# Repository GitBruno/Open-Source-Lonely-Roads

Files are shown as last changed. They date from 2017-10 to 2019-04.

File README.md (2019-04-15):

# Open Source Lonely Roads
An active linear power distribution board for Eurorack.

> __WARNING!__ ⚡️ Please be aware of the risks associated with electronics and take relevant precautions.

## Features
- High voltage distribution boards
- Dedicated linear regulators for each header
- Switchable status LEDs
- Star grounding on dedicated layer
- Wide traces
- Reverse voltage protection
- Bypass capacitors
- Ultra low noise
- Ultra low inter-module noise
- Protection + safety features
- 3u boat compatible
- Standard 84hp (19”) and 104hp compatible
- Wide range of voltage input options
- Multiple CV/Gate busses possible. (Have conflicting modules play nice together)
- Optional addons (Voltage converter/startup delay)

Please read the [Wiki](https://github.com/GitBruno/Open-Source-Lonely-Roads/wiki) to find out more about this project.

## Licence
Open Source Lonely Roads by [Robert D Jordan](http://www.catfullofghosts.com/) and [Bruno Herfst](http://brunoherfst.com/) is licensed under a [Creative Commons Attribution 4.0 International License](LICENCE.md).



WaveGuides

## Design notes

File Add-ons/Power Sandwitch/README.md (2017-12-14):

# Power Sandwitch
An add-on for the Open Source Lonely Roads power distribution boards. This add-on makes the OSLR boards eat a wide variety of power supplies. 

So besides any +- 15v cage power supply the OSLR can be powered off:

- Single 9-18v DC supply
- Dual 15+v DC supplies (E.g. 2 laptop chargers)
- Single 14-36v supply (Cheap!)

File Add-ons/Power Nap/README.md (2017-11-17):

# Power Nap
An add-on for the Open Source Lonely Roads power distribution boards. This add-on adds a 555 timer circuit to delay startup time.

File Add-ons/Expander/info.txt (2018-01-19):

An expander for the Lonely Roads that breaks out each individual eurorack power header into 2 right angle 16pin
and one vertical 10pin header. Attaches ontop of Lonely Roads busboard like an arduino sheild.
Each set of 3 power headers is isolated from all others.

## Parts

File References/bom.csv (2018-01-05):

Qty | Part Number | Description | Package | Manufacturer | Suggested Suppliers | Mouser Part No | Sub/Comments | Part ID.
6 |  | Headers | 2X08 |  |  | 538-15-47-7616 |  | JP1,JP2,JP3,JP4,JP5,JP6
6 | 7805 | Voltage Regulator | 78MXXS |  |  | 511-L7805CV |  | 7805,2,5,8,11,14
6 | 7812 | Voltage Regulator | 78MXXS |  |  | 511-L7812CV |  | 7812,1,4,7,10,13
6 | 7912 | Voltage Regulator | 79XXS |  |  | 926-LM7912CT/NOPB |  | 3,6,9,12,15,7912
6 | 220 | Resistor |  |  |  | 660-MF1/4LCT52R221J | 1/4w | R1,R4,R7,R10,R13,R16
12 | 550 | Resistor |  |  |  | 660-MF1/4LCT52R511J | Arround 500/510 is fine too | R2,R3,R5,R6,R8,R9,R11,R12,R14,R15,R17,R18
3 |  | Terminal |  |  |  |  | need Mouser Part No equivilent | SCREW_+15,SCREW_-15,SCREW_GND
18 | 0.1uf | Capacitor |  |  |  | 75-1C20X7R103K050B |  | C1,C2,C3,C6,C7,C12,C13,C14,C15,C19,C20,C21,C24,C25,C26,C29,C30,C31
12 | 10uf | Capacitor | CPOL-RADIAL-10UF-25V |  |  | 647-UPW1E100MDD6 |  | C4,C5,C8,C9,C16,C17,C22,C23,C27,C28,C32,C33
3 | 100uf | Capacitor | CPOL-RADIAL-100UF-25V |  |  | 647-UVY1E101MDD | board needs better spacing for these | C10,C11,C18
12 | 1N4004 | Diode | DO41-10 |  |  | 621-1N4004 |  | D1,D2,D3,D4,D7,D8,D9,D10,D11,D12,D13,D14
1 |  | Switch | EG1218 |  |  | 612-EG1218 | can just use a piece of wire if you don't need to turn the on and off. | S1
3 | PIN2F061.200 | Terminal | F061.200 |  |  | 571-624091 |  | J1_+15,J2_+15,J3_GND,J4_GND,J5_-15,J6_-15
18 |  | LED | LED3MM |  |  | 696-SSF-LX3P74GD | Use 3 colours one for +12v, -12v and 5v | LED1,LED2,LED3,LED4,LED5,LED6,LED7,LED8,LED9,LED10,LED11,LED12,LED13,LED14,LED15,LED16,LED17,LED18
2 | BA296 | Rectifier | P2-15 |  |  | 833-1N5400-TP |  | D5,D6
2 | PTCPTH | Reseting Fuse | PTC |  |  | 652-MF-R300-2 |  | F1,F2
2 |  | Ferrite Beads 7A Leaded EMIFIL | RLB0912 |  |  | 81-BL02RN2R1M2B |  | U$1,U$2
3 |  | Terminals 6.3MM VERT PCB SPD TERM-10K/RL |  |  |  | 855-S409-46 |  | J1_+15,J2_+15,J3_GND,J4_GND,J5_-15,J6_-15
? |  | 6.3mm Female Spade Crimp |  |  |  | 517-7250 | connectors used to link busboards together, or link to power supply

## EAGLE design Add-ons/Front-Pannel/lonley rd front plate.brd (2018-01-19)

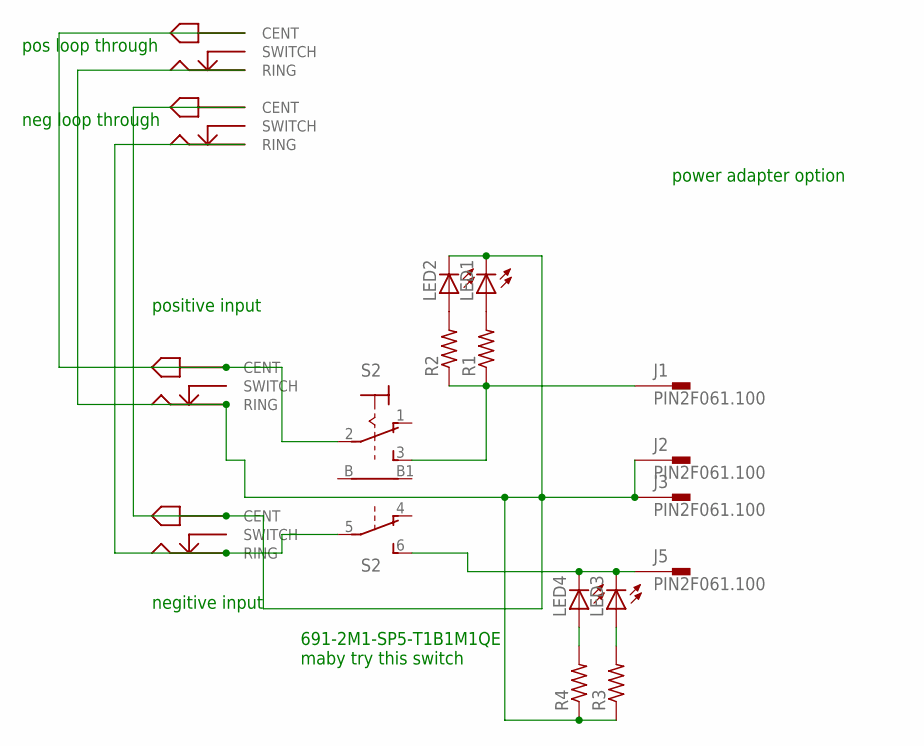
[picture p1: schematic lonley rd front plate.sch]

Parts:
J1, J2, J3, J5: PIN2F061.100; F061.100
LED1, LED2, LED3, LED4: LED3MM
R1, R2, R3, R4: R-US_0309/V; 0309V
S2: 9070-2W
U$1, U$2, U$3, U$4: PJ-066A_DC_JACK

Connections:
unnamed: LED2.A, R2.2
unnamed: J2.A1, J2.A2, J3.A1, J3.A2, LED1.K (C), LED2.K (C), R3.1, R4.1, U$1.RING, U$2.CENT, U$3.RING, U$4.CENT
unnamed: J1.A1, J1.A2, R1.1, R2.1, S2.3 (S)
unnamed: J5.A1, J5.A2, LED3.K (C), LED4.K (C)
unnamed: S2.2, U$1.CENT, U$3.CENT
unnamed: U$2.RING, U$4.RING
unnamed: LED1.A, R1.2
unnamed: LED3.A, R3.2
unnamed: LED4.A, R4.2

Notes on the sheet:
positive input
negitive input
pos loop through
neg loop through
691-2M1-SP5-T1B1M1QE maby try this switch
power adapter option

Board: 2 copper layers, 17 parts (0 on the bottom side), 9 nets, no tracks yet.

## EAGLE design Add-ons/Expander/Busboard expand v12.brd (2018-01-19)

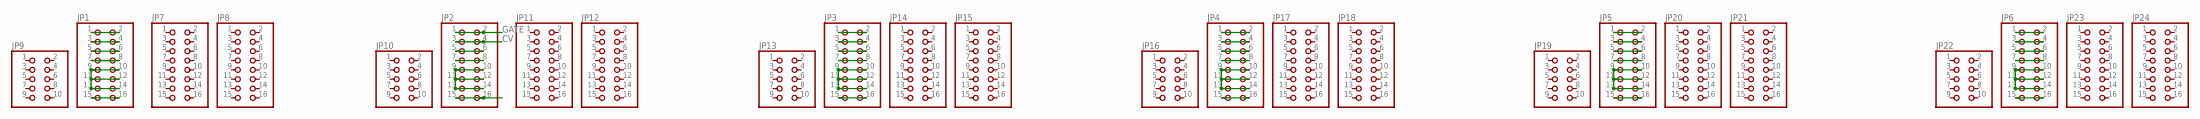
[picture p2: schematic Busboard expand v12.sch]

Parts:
JP1, JP2, JP3, JP4, JP5, JP6: PINHD-2X8; 2X08
JP7, JP8, JP11, JP12, JP14, JP15, JP17, JP18, JP20, JP21, JP23, JP24: PINHD-2X8/90; 2X08/90
JP9, JP10, JP13, JP16, JP19, JP22: PINHD-2X5; 2X05

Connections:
CV: JP1.3, JP1.4, JP2.3, JP2.4, JP3.3, JP3.4, JP4.3, JP4.4, JP5.3, JP5.4, JP6.3, JP6.4
GATE: JP1.1, JP1.2, JP2.1, JP2.2, JP3.1, JP3.2, JP4.1, JP4.2, JP5.1, JP5.2, JP6.1, JP6.2
unnamed: JP2.9, JP2.10, JP2.11, JP2.12, JP2.13, JP2.14
unnamed: JP3.9, JP3.10, JP3.11, JP3.12, JP3.13, JP3.14
unnamed: JP1.9, JP1.10, JP1.11, JP1.12, JP1.13, JP1.14
unnamed: JP3.15, JP3.16
unnamed: JP4.9, JP4.10, JP4.11, JP4.12, JP4.13, JP4.14
unnamed: JP1.15, JP1.16
unnamed: JP5.9, JP5.10, JP5.11, JP5.12, JP5.13, JP5.14
unnamed: JP1.7, JP1.8
unnamed: JP4.15, JP4.16
unnamed: JP6.9, JP6.10, JP6.11, JP6.12, JP6.13, JP6.14
unnamed: JP6.15, JP6.16
unnamed: JP6.7, JP6.8
unnamed: JP2.15, JP2.16
unnamed: JP2.5, JP2.6
unnamed: JP1.5, JP1.6
unnamed: JP2.7, JP2.8
unnamed: JP3.5, JP3.6
unnamed: JP5.15, JP5.16
unnamed: JP5.7, JP5.8
unnamed: JP3.7, JP3.8
unnamed: JP4.7, JP4.8
unnamed: JP4.5, JP4.6
unnamed: JP5.5, JP5.6
unnamed: JP6.5, JP6.6

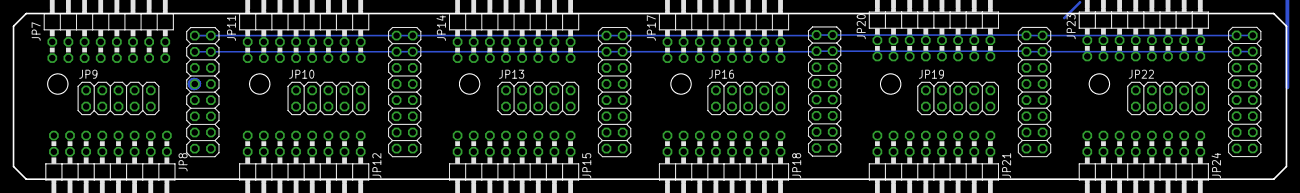
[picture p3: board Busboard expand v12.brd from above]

Board: 2 copper layers, 200.2 x 26.1 mm, 24 parts (0 on the bottom side), 26 nets.

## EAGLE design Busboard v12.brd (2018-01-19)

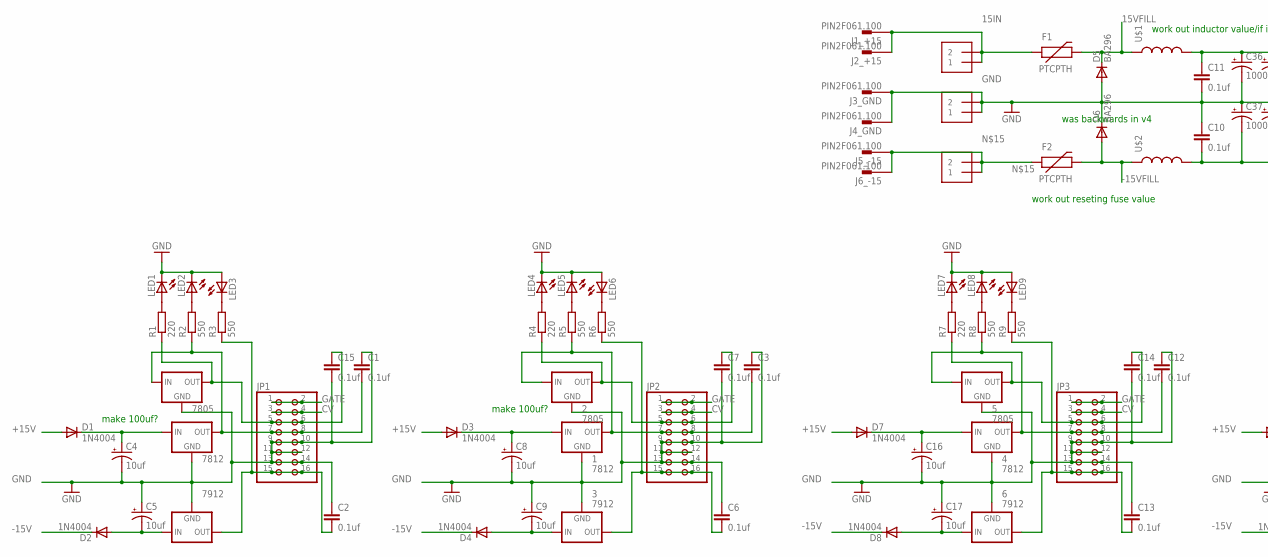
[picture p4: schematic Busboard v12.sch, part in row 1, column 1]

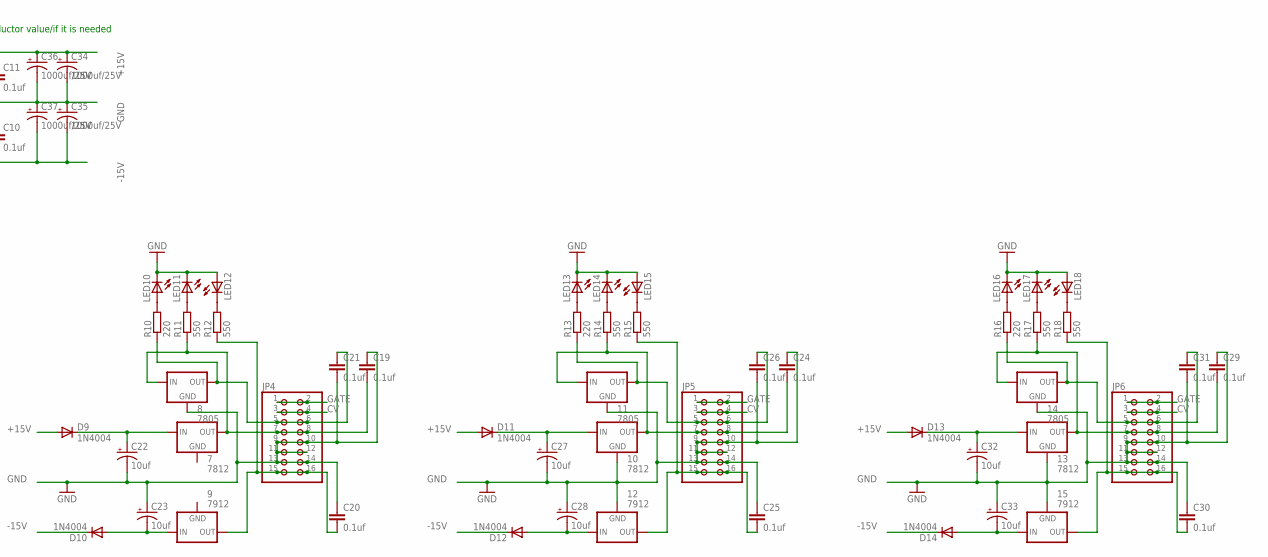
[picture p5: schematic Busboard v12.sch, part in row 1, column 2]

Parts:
1, 4, 7, 10, 13: 7812; 78MXXS
2, 5, 8, 11, 14: 7805; 78MXXS
3, 6, 9, 12, 15: 7912; 79XXS
7805, 7812: 78MXXS
7912: 79XXS
+15V: 1X2-3.5MM
-15V: 1X2-3.5MM
C1, C2, C3, C6, C7, C10, C11, C12, C13, C14, C15, C19, C20, C21, C24, C25, C26, C29, C30, C31: 0.1uf; CAP-PTH-SMALL-KIT
C4, C5, C8, C9, C16, C17, C22, C23, C27, C28, C32, C33: 10uf; CPOL-RADIAL-10UF-25V
C34, C35, C36, C37: 1000uf/25V; CPOL-RADIAL-1000UF-25V-KIT
D1, D2, D3, D4, D7, D8, D9, D10, D11, D12, D13, D14: 1N4004; DO41-10
D5, D6: BA296; P2-15
F1, F2: PTCPTH; PTC
GND: 1X2-3.5MM
J1_+15, J2_+15, J3_GND, J4_GND, J5_-15, J6_-15: PIN2F061.100; F061.100
JP1, JP2, JP3, JP4, JP5, JP6: PINHD-2X8; 2X08
LED1, LED2, LED3, LED4, LED5, LED6, LED7, LED8, LED9, LED10, LED11, LED12, LED13, LED14, LED15, LED16, LED17, LED18: LED3MM
R1, R4, R7, R10, R13, R16: 220; 0207/5V
R2, R3, R5, R6, R8, R9, R11, R12, R14, R15, R17, R18: 550; 0207/5V
U$1, U$2: INDUCTORRLB0912; RLB0912

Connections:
15IN: +15V.1, +15V.2, F1.P$1 (1), J1_+15.A1, J1_+15.A2, J2_+15.A1, J2_+15.A2
15VFILL: D5.C, F1.P$2 (2), U$1.1
+15V: C11.1, C34.+, C36.+, D1.A, D3.A, D7.A, D9.A, D11.A, D13.A, U$1.2
-15V: C10.2, C35.-, C37.-, D2.C, D4.C, D8.C, D10.C, D12.C, D14.C, U$2.2
-15VFILL: D6.A, F2.P$2 (2), U$2.1
CV: JP1.3, JP1.4, JP2.3, JP2.4, JP3.3, JP3.4, JP4.3, JP4.4, JP5.3, JP5.4, JP6.3, JP6.4
GATE: JP1.1, JP1.2, JP2.1, JP2.2, JP3.1, JP3.2, JP4.1, JP4.2, JP5.1, JP5.2, JP6.1, JP6.2
GND: 1.GND, 2.GND, 3.GND, 4.GND, 5.GND, 6.GND, 8.GND, 10.GND, 11.GND, 12.GND, 13.GND, 14.GND, 15.GND, 7805.GND, 7812.GND, 7912.GND, C1.1, C2.1, C3.1, C4.2 (-), C5.1 (+), C6.1, C7.2, C8.2 (-), C9.1 (+), C10.1, C11.2, C12.1, C13.1, C14.2, C15.2, C16.2 (-), C17.1 (+), C19.1, C20.1, C21.2, C22.2 (-), C23.1 (+), C24.1, C25.1, C26.2, C27.2 (-), C28.1 (+), C29.1, C30.1, C31.2, C32.2 (-), C33.1 (+), C34.-, C35.+, C36.-, C37.+, D5.A, D6.C, GND.1, GND.2, J3_GND.A1, J3_GND.A2, J4_GND.A1, J4_GND.A2, JP1.9, JP1.10, JP1.11, JP1.12, JP1.13, JP1.14, JP2.9, JP2.10, JP2.11, JP2.12, JP2.13, JP2.14, JP3.9, JP3.10, JP3.11, JP3.12, JP3.13, JP3.14, JP4.9, JP4.10, JP4.11, JP4.12, JP4.13, JP4.14, JP5.9, JP5.10, JP5.11, JP5.12, JP5.13, JP5.14, JP6.9, JP6.10, JP6.11, JP6.12, JP6.13, JP6.14, LED1.K (C), LED2.K (C), LED3.A, LED4.K (C), LED5.K (C), LED6.A, LED7.K (C), LED8.K (C), LED9.A, LED10.K (C), LED11.K (C), LED12.A, LED13.K (C), LED14.K (C), LED15.A, LED16.K (C), LED17.K (C), LED18.A
unnamed: 7912.IN, C5.2 (-), D2.A
unnamed: 7912.OUT, C2.2, JP1.15, JP1.16, R3.1
unnamed: 6.OUT, C13.2, JP3.15, JP3.16, R9.1
unnamed: 7812.IN, C4.1 (+), D1.C
unnamed: 7805.IN, 7812.OUT, C1.2, JP1.7, JP1.8, R2.1
unnamed: 3.OUT, C6.2, JP2.15, JP2.16, R6.1
unnamed: 6.IN, C17.2 (-), D8.A
unnamed: 3.IN, C9.2 (-), D4.A
unnamed: 1.IN, C8.1 (+), D3.C
unnamed: LED1.A, R1.2
unnamed: LED2.A, R2.2
unnamed: -15V.1, -15V.2, F2.P$1 (1), J5_-15.A1, J5_-15.A2, J6_-15.A1, J6_-15.A2
unnamed: LED3.K (C), R3.2
unnamed: 1.OUT, 2.IN, C3.2, JP2.7, JP2.8, R5.1
unnamed: 4.IN, C16.1 (+), D7.C
unnamed: 2.OUT, C7.1, JP2.5, JP2.6, R4.1
unnamed: 7805.OUT, C15.1, JP1.5, JP1.6, R1.1
unnamed: LED4.A, R4.2
unnamed: LED5.A, R5.2
unnamed: LED6.K (C), R6.2
unnamed: 4.OUT, 5.IN, C12.2, JP3.7, JP3.8, R8.1
unnamed: 5.OUT, C14.1, JP3.5, JP3.6, R7.1
unnamed: LED7.A, R7.2
unnamed: LED8.A, R8.2
unnamed: LED9.K (C), R9.2
unnamed: 9.OUT, C20.2, JP4.15, JP4.16, R12.1
unnamed: 9.IN, C23.2 (-), D10.A
unnamed: 7.IN, C22.1 (+), D9.C
unnamed: 7.OUT, 8.IN, C19.2, JP4.7, JP4.8, R11.1
unnamed: 8.OUT, C21.1, JP4.5, JP4.6, R10.1
unnamed: LED10.A, R10.2
unnamed: LED11.A, R11.2
unnamed: LED12.K (C), R12.2
unnamed: 15.OUT, C30.2, JP6.15, JP6.16, R18.1
unnamed: 12.OUT, C25.2, JP5.15, JP5.16, R15.1
unnamed: 12.IN, C28.2 (-), D12.A
unnamed: 10.IN, C27.1 (+), D11.C
unnamed: 10.OUT, 11.IN, C24.2, JP5.7, JP5.8, R14.1
unnamed: 11.OUT, C26.1, JP5.5, JP5.6, R13.1
unnamed: LED13.A, R13.2
unnamed: LED14.A, R14.2
unnamed: LED15.K (C), R15.2
unnamed: 15.IN, C33.2 (-), D14.A
unnamed: 13.IN, C32.1 (+), D13.C
unnamed: 13.OUT, 14.IN, C29.2, JP6.7, JP6.8, R17.1
unnamed: 14.OUT, C31.1, JP6.5, JP6.6, R16.1
unnamed: LED16.A, R16.2
unnamed: LED17.A, R17.2
unnamed: LED18.K (C), R18.2

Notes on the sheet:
work out reseting fuse value
work out inductor value/if it is needed
was backwards in v4
make 100uf?

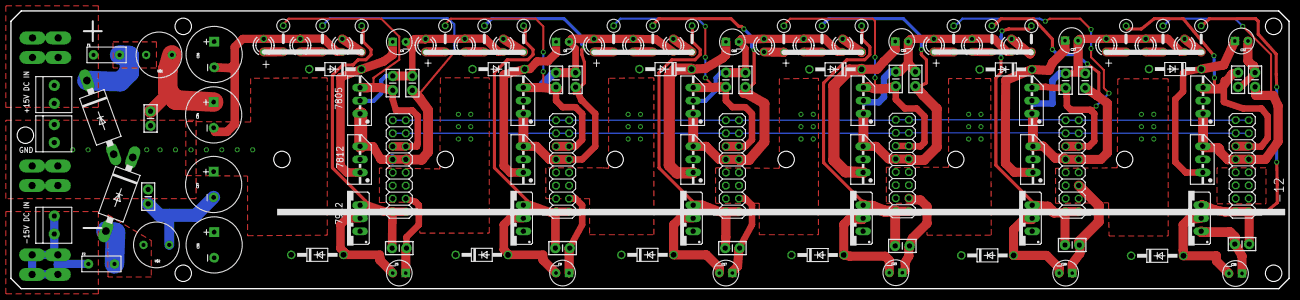
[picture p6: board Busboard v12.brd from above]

Board: 2 copper layers, 248.5 x 54.0 mm, 123 parts (0 on the bottom side), 57 nets.

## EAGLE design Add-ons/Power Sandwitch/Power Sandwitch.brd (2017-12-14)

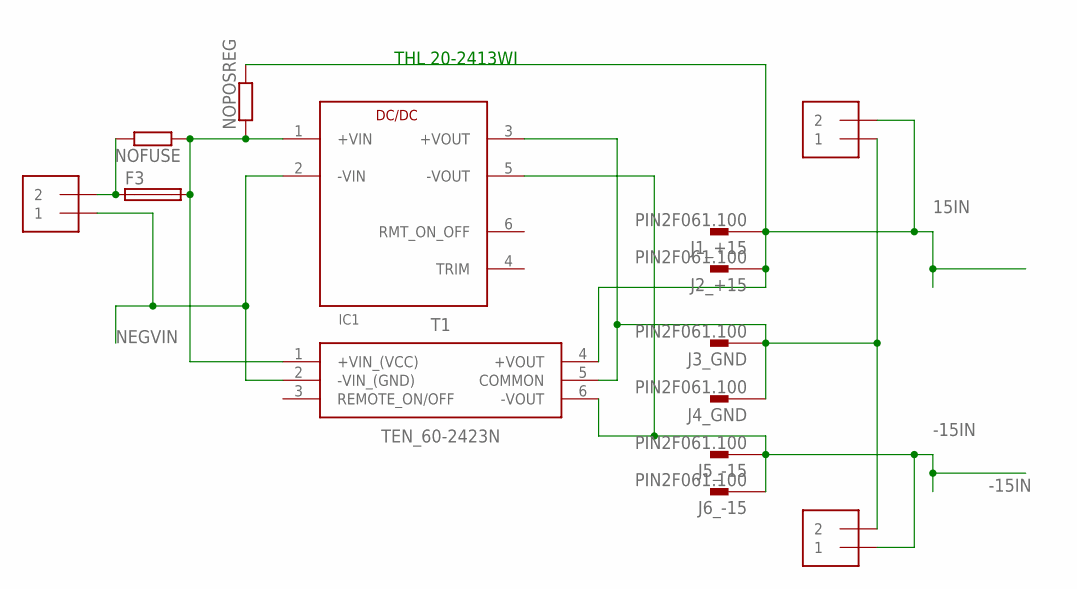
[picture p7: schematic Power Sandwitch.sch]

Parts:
DC_IN, DC_IN1, DC_IN2: 1X2-3.5MM
F3: GSH15
IC1: THL_20WI_SERIES
J1_+15, J2_+15, J3_GND, J4_GND, J5_-15, J6_-15: PIN2F061.100; F061.100
NOFUSE: SMT-REF
NOPOSREG: SMT-REF
T1: TEN_60-2423N; TEN60-2423N

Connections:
15IN: DC_IN1.2, J1_+15.A1, J1_+15.A2, J2_+15.A1, J2_+15.A2, NOPOSREG.1, T1.4 (+VOUT)
-15IN: DC_IN2.1, IC1.5 (-VOUT), J5_-15.A1, J5_-15.A2, J6_-15.A1, J6_-15.A2, T1.6 (-VOUT)
unnamed: DC_IN1.1, DC_IN2.2, IC1.3 (+VOUT), J3_GND.A1, J3_GND.A2, J4_GND.A1, J4_GND.A2, T1.5 (COMMON)
unnamed: F3.2, IC1.1 (+VIN), NOFUSE.2, NOPOSREG.2, T1.1 (+VIN_(VCC))
unnamed: DC_IN.2, F3.1, NOFUSE.1
NEGVIN: DC_IN.1, IC1.2 (-VIN), T1.2 (-VIN_(GND))

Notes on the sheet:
THL 20‑2413WI

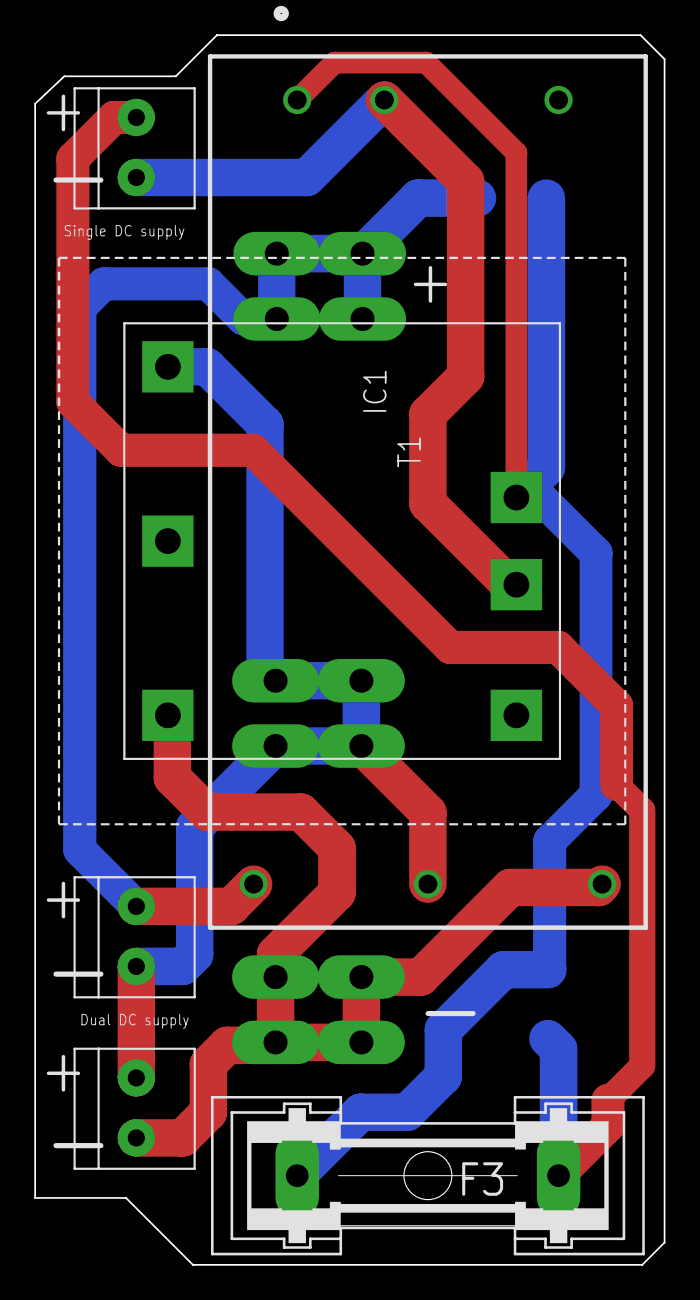
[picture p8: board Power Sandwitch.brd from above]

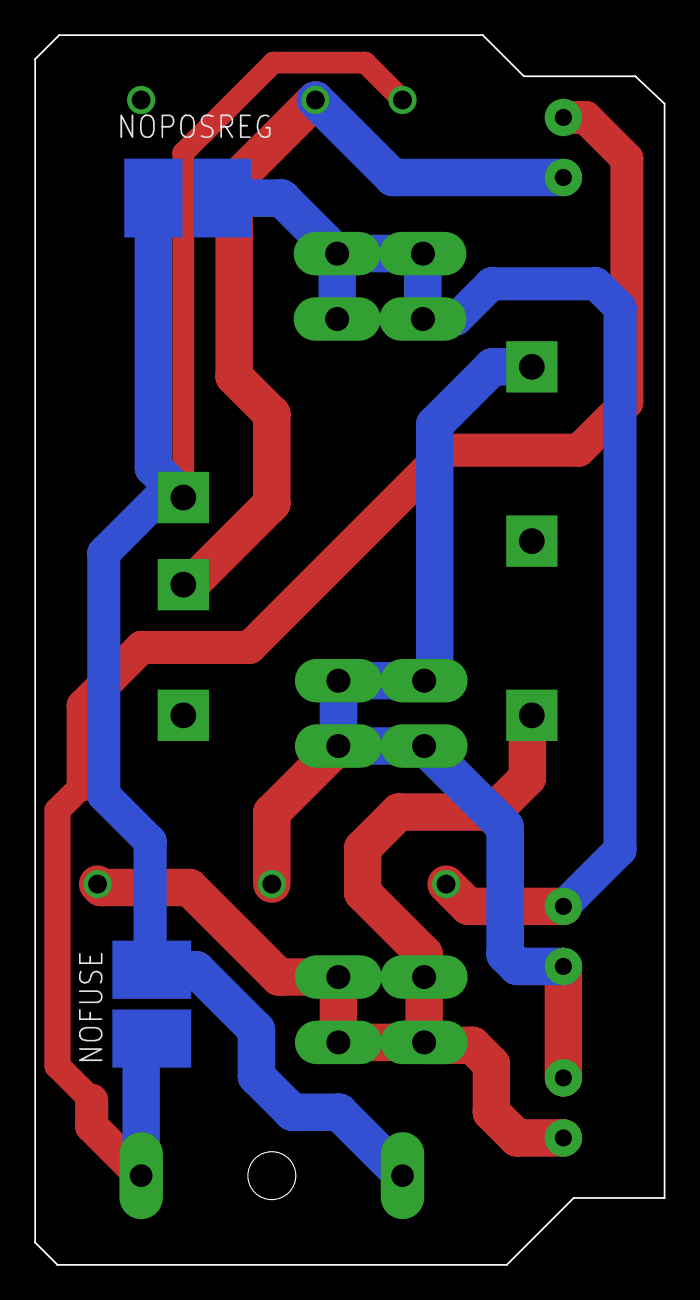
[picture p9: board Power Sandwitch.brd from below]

Board: 2 copper layers, 36.7 x 71.7 mm, 14 parts (2 on the bottom side), 6 nets.

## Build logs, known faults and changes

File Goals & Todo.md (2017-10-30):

# PROS
- Ultra low noise
- Ultra low inter-module noise
- Protection + safety features
- 3u boat compatible (not taller then 3u)
- Standard 84hp (19") and 104hp compatible (not wider then 50hp)
- Wide range of voltage input solutions
- Good heat handling/dissipation
- Good price
- Good documentation
- Readily avalible parts
- A range of PCB manufaturing options (design not totaly resticted by super thick pcb or any kind of special treatment)

# CONS
- This system uses more power in standby then a passive system  
- This system is less efficient then a passive system (duh)  
- ~~This system does not distribute CV and gate signals~~  

# TODO
- Power Input 15–21V (15 is best, most laptop chargers are 19V) Surge capability value?  
- Solve power input question for external power supply, TPS84259? 
- Re arrange pcb design for better spacing (Make space for heatsinks and bigger caps)  
- Move bigger caps before regulators (Smaller noise caps behind is fine)  
- Bigger caps on input rails  
- Solve magic smoke from negative input cap (16v may not be high enough on the caps, should have gone 30v+)  
- Put diodes after fuses to stop flooding on a critical fail  
- Create place for testing logs  
- Update PCB silk layer before next prototype  
- Create decision matrix on different configurations
- Test prototype in system  
- Do death test with video  
- Create clip on dc module with perf board (Test clipping strength)
– Create Eagle clip on module template. And add specs to Wiki
– Create Wiki entry on how to patch CV-GATE over busboard.
– Add graphics to board, incl. OSHW cert brand and labeling

# DONE
- first prototype built and tested  
- fix error in v4 diode protection  
- Organise Open Source Certificate

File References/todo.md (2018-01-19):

# TODO
- Power Input 15–21V (15 is best, most laptop chargers are 19V) Surge capability value?  
- Solve power input question for external power supply, TPS84259?  
- Create place for testing logs  
- Update PCB silk layer before next prototype  
- Create decision matrix on different configurations
- Test prototype in system  
- Do death test with video  
- Create clip on dc module with perf board (Test clipping strength)
– Create Eagle clip on module template. And add specs to Wiki

# DONE
- first prototype built and tested  
- fix error in v4 diode protection  
- Organise Open Source Certificate
- Fix cap error
– Add graphics to board, incl. OSHW cert brand and labeling
– ///no longer rekuvent /// Create Wiki entry on how to patch CV-GATE over busboard.
- Put diodes after fuses to stop flooding on a critical fail  
- Re arrange pcb design for better spacing (Make space for heatsinks and bigger caps)  
- Move bigger caps before regulators (Smaller noise caps behind is fine)  
- Bigger caps on input rails  
- Solve magic smoke from negative input cap (16v may not be high enough on the caps, should have gone 30v+)

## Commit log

2017-07-20 Create Compatible DC Power Supplies.txt
2017-07-21 Update Compatible DC Power Supplies.md
2017-08-13 Add files via upload
    Here are the eagle files for the prototype busboard.
    [Busboard v4.brd, Busboard v4.sch]
2017-08-17 Update Schematic PDF to fit on page
2017-09-03 Start BOM
    [BOM v4.csv]
2017-09-05 Update BOM with mouser parts
    [BOM v4.csv]
2017-09-21 Update BOM v4.csv
    [BOM v4.csv]
2017-09-23 Rename Design Files/Busboard v4.sch to Design Files/V4 files/Busboard v4.sch
    [Busboard v4.sch]
2017-09-23 Rename Design Files/Busboard v4.brd to Design Files/V4 files/Busboard v4.brd
    [Busboard v4.brd]
2017-09-23 Rename Design Files/BOM v4.csv to Design Files/V4 files/BOM v4.csv
    [BOM v4.csv]
2017-09-23 Delete Busboard v4 Board.pdf
    moved to sub directory
2017-09-23 Add files via upload
    pdf for board design v4
2017-09-23 Delete Busboard v4 Schematic.pdf
    moving to sub folder to make way for v5
2017-09-23 Rename Design Files/gerb v4/Busboard v4.GBL to Design Files/gerb v4/V4 files/gerb v4/Busboard v4.GBL
    [Busboard v4.GBL]
2017-09-23 Delete Busboard v4.GBO
    has error, dont want people using it
    [Busboard v4.GBO]
2017-09-23 Delete Busboard v4.GBL
    has error, don't want people using it
    [Busboard v4.GBL]
2017-09-23 Delete Busboard v4.GTL
    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
    [Busboard v4.GTL]
2017-09-23 Delete Busboard v4.GTO
    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
    [Busboard v4.GTO]
2017-09-23 Delete Busboard v4.GTP
    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
    [Busboard v4.GTP]
2017-09-23 Delete Busboard v4.GTS
    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
    [Busboard v4.GTS]
2017-09-23 Add files via upload
    V5 files with the last port wiring fixed
    [Busboard v5.brd, Busboard v5.sch]
2017-10-04 updated Bom
    [BOM v4.csv]
2017-11-14 the finished files for v10
    i couldn't seem to open any of the graphics files to add them, but found a good tourotrial for adding graphics as svg's which look stones easyer, Open source logo is on there tho
    https://learn.sparkfun.com/tutorials/importing-custom-images-into-eagle/all
    [Busboard v10.brd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]
2017-12-03 v12
    - Aligned mounting holes
    - All LEDS same orientation
    [Busboard v12.brd, Busboard v12.sch, bom.csv]
2017-12-10 Added OSLR + OSHWA marks
    [Busboard v12.brd]
2017-12-10 Add mounting template
2017-12-14 updated .sch and .brd
    i did another check over everything to make sure it lined up with the power sandwich, and added a 0.1uf 50v cap just after the inductor/ferrite bead to hopefully reduce ripple at the input.
    [Busboard v12.brd, Busboard v12.sch]
2017-12-14 Update README.md
    got to check the reg inputs but i think this is the specs for the single negative rail regulator.
2017-12-14 Add files via upload
    latest power sandwitch files updated
    [Power Sandwitch.brd, Power Sandwitch.sch]
2018-01-05 updated with latest parts
    [bom.csv]
2018-01-19 Add files via upload
    Fixing some dumb mistakes based on building the v12 prototype. had some backward caps and should have picked a lower trip thresh for the polyfuse.
    [Busboard v12.brd, Busboard v12.sch]
2018-01-19 Add files via upload
    need to check there is no collision with the 1000uf caps on the .brd file
    [Busboard expand v12.brd, Busboard expand v12.sch]

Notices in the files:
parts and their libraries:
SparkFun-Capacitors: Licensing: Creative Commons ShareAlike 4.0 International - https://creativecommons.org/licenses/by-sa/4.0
